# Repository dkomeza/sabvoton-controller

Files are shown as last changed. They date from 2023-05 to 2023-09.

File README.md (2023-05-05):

# sabvoton-controller

A controller for the sabvoton ebike esc.

## Pinout reference

```
---------------------------------------------------
| 01 | 02 | 03 | 04 | 05 | 06 | 07 | 08 | 09 | 10 |
---------------------------------------------------
| 11 | 12 | 13 | 14 | 15 | 16 | 17 | 18 | 19 | 20 |
---------------------------------------------------
| 21 | 22 | 23 | 24 | 25 | 26 | 27 | 28 | 29 | 30 |
---------------------------------------------------
```

- 01: speed (0V - Battery voltage)
- 02: programming (brown-blue)
- 03: low speed (controlled by gnd)
- 04: high speed (controlled by gnd)
- 05: brake (controlled by gnd)
- 06: service (unused)
- 07: empty
- 08: 5V
- 09: 5V square hall sensor (speedometer)
- 10: empty
- 11: battery voltage
- 12: programming (blue-yellow)
- 13: programming (green-black)
- 14: programming (red-black)
- 15: brake (controlled by 12v)
- 16: reverse (controlled by gnd)
- 17: gnd
- 18: gnd
- 19: throttle (0V - 5V)?
- 20: ignition (controlled by battery voltage)
- 21: engine phase (anti-theft)
- 22: empty
- 23: regen (controlled by gnd)
- 24: soft-start (connected to 26)
- 25: cruise control (controlled by gnd)
- 26: soft-start (connected to 24)
- 27: gnd
- 28: gnd
- 29: alarm (controlled by gnd)
- 30: service (unused)

## Working with the controller

### Connectors

- [x] 1: programming connector (same as the original)
- [x] 2: usb connector (for programming the arduino)

### Functions:

- [x] 1: set current gear (low, mid, high) - pins 03, 04
- [x] 2: set motor power based on the torque sensor input - pin 19
- [x] 3: read battery voltage - pin 11
- [x] 4: turn controller on/off - pin 20
- [x] 5: enable/disable soft start - pins 24, 26
- [x] 6: get engine temperature - white wire
- [x] 7: get engine rpm - white wire
- [x] 8: get controller temperature - additional sensor
- [x] 9: get battery temperature - additional sensor
- [x] 10: send data to the display - additional display
- [x] 11: get data from the display - additional display

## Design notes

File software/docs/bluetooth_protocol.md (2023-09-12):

# Bluetooth Serial protocol

```
-----------------------------
| Num | Value | Description |
-----------------------------
|  0  |  0x41 | Start byte  |
|  1  |  0xYY | Message ID  |
|  2  |  0xYY | Instruction |
| 3 - |  0xYY | Parameters  |
| n-1 |  0x0D | End byte 1  |
|  n  |  0x0A | End byte 2  |
-----------------------------
```

## Message ID

```
-----------------------
| Value | Description |
-----------------------
|  0x01 | Ping        |
|  0x02 | Settings    |
|  0x03 | Control     |
|  0x04 | Status      |
-----------------------
```

### Ping

```
-----------------------
| Value | Description |
-----------------------
|  0x01 | Ping        |
-----------------------
```

### Settings

```
-----------------------
| Value | Description |
-----------------------
| 0x01  | Throttle    |
-----------------------
```

#### Throttle

##### Parameter 0

```
---------------------------------
| Value | Description           |
---------------------------------
| 0x01  | Throttle min          |
| 0x02  | Throttle max          |
| 0x03  | Throttle save         |
---------------------------------
```

##### Parameter 1

```
--------------------------
| Value | Description    |
--------------------------
| 0x00  | Throttle value |
--------------------------
```

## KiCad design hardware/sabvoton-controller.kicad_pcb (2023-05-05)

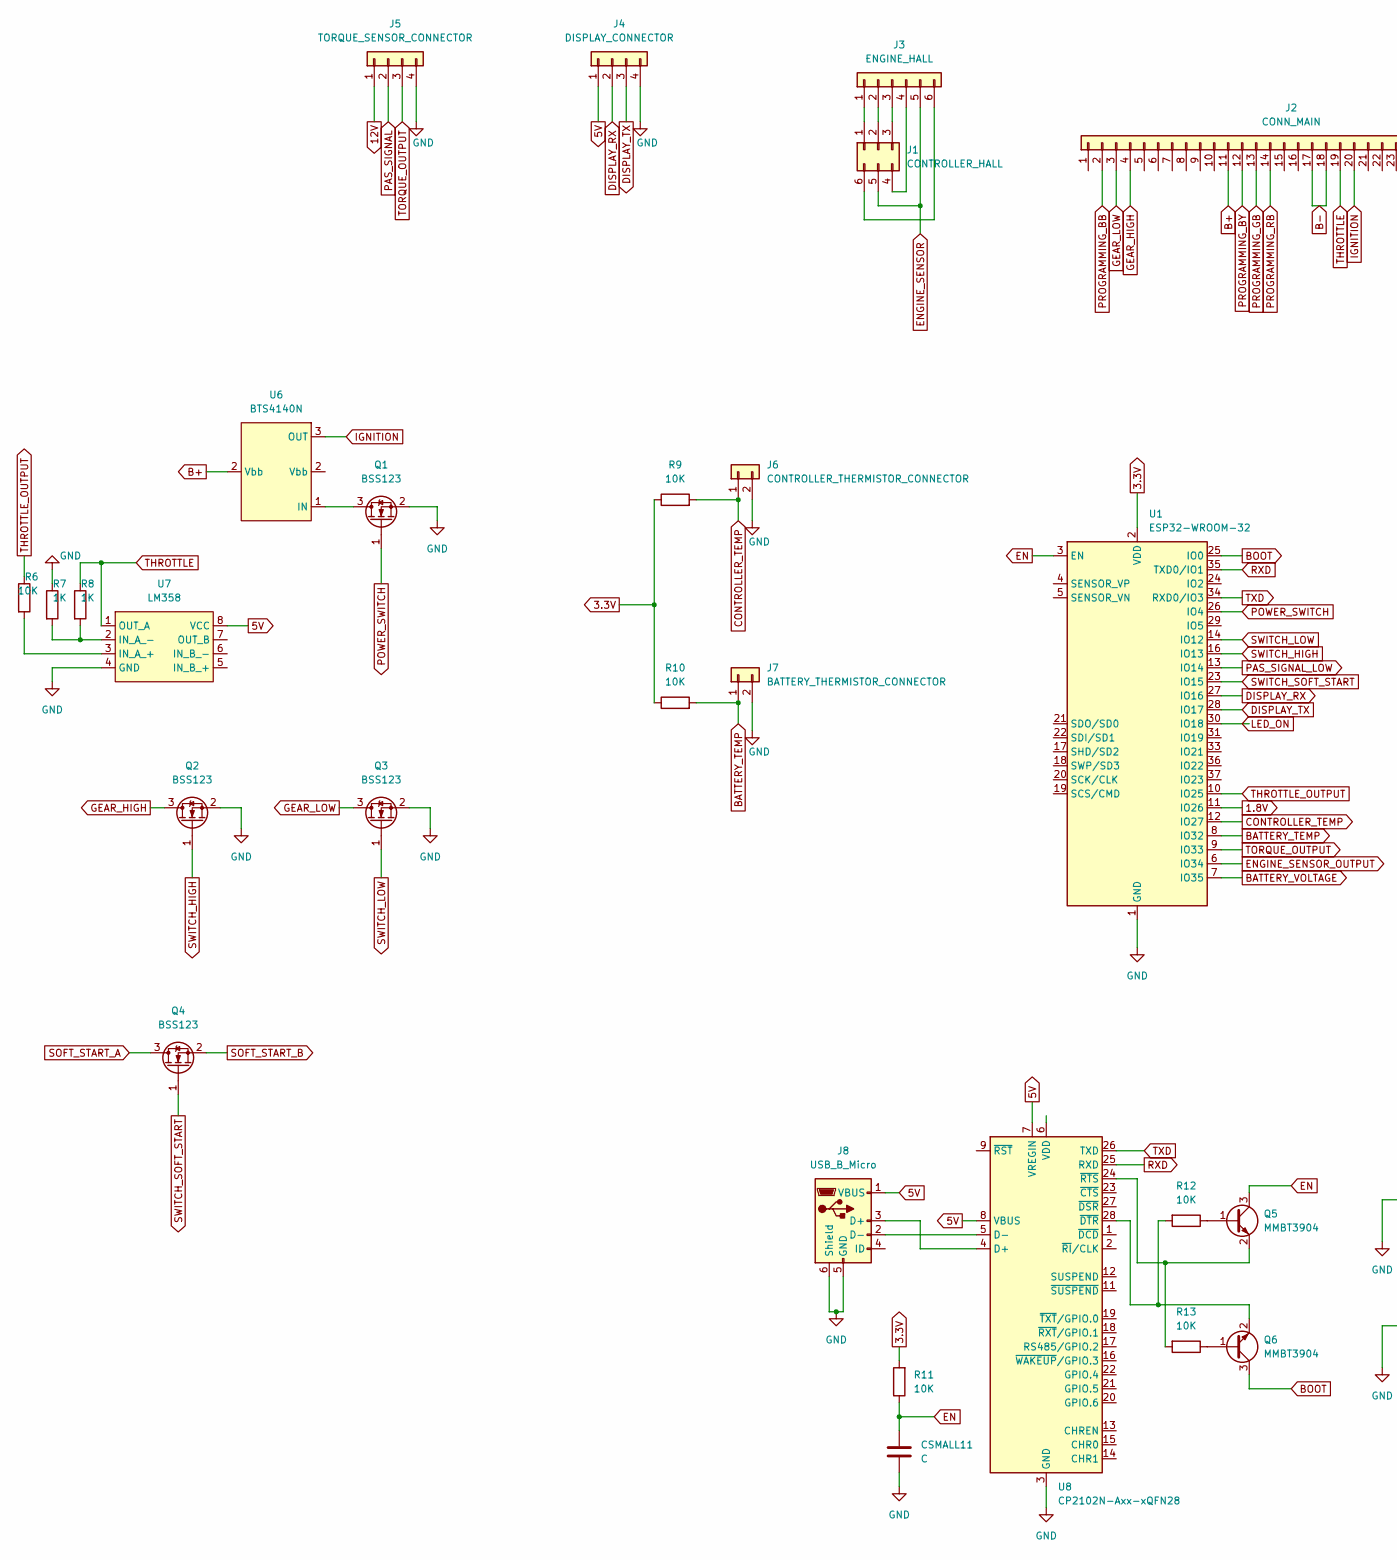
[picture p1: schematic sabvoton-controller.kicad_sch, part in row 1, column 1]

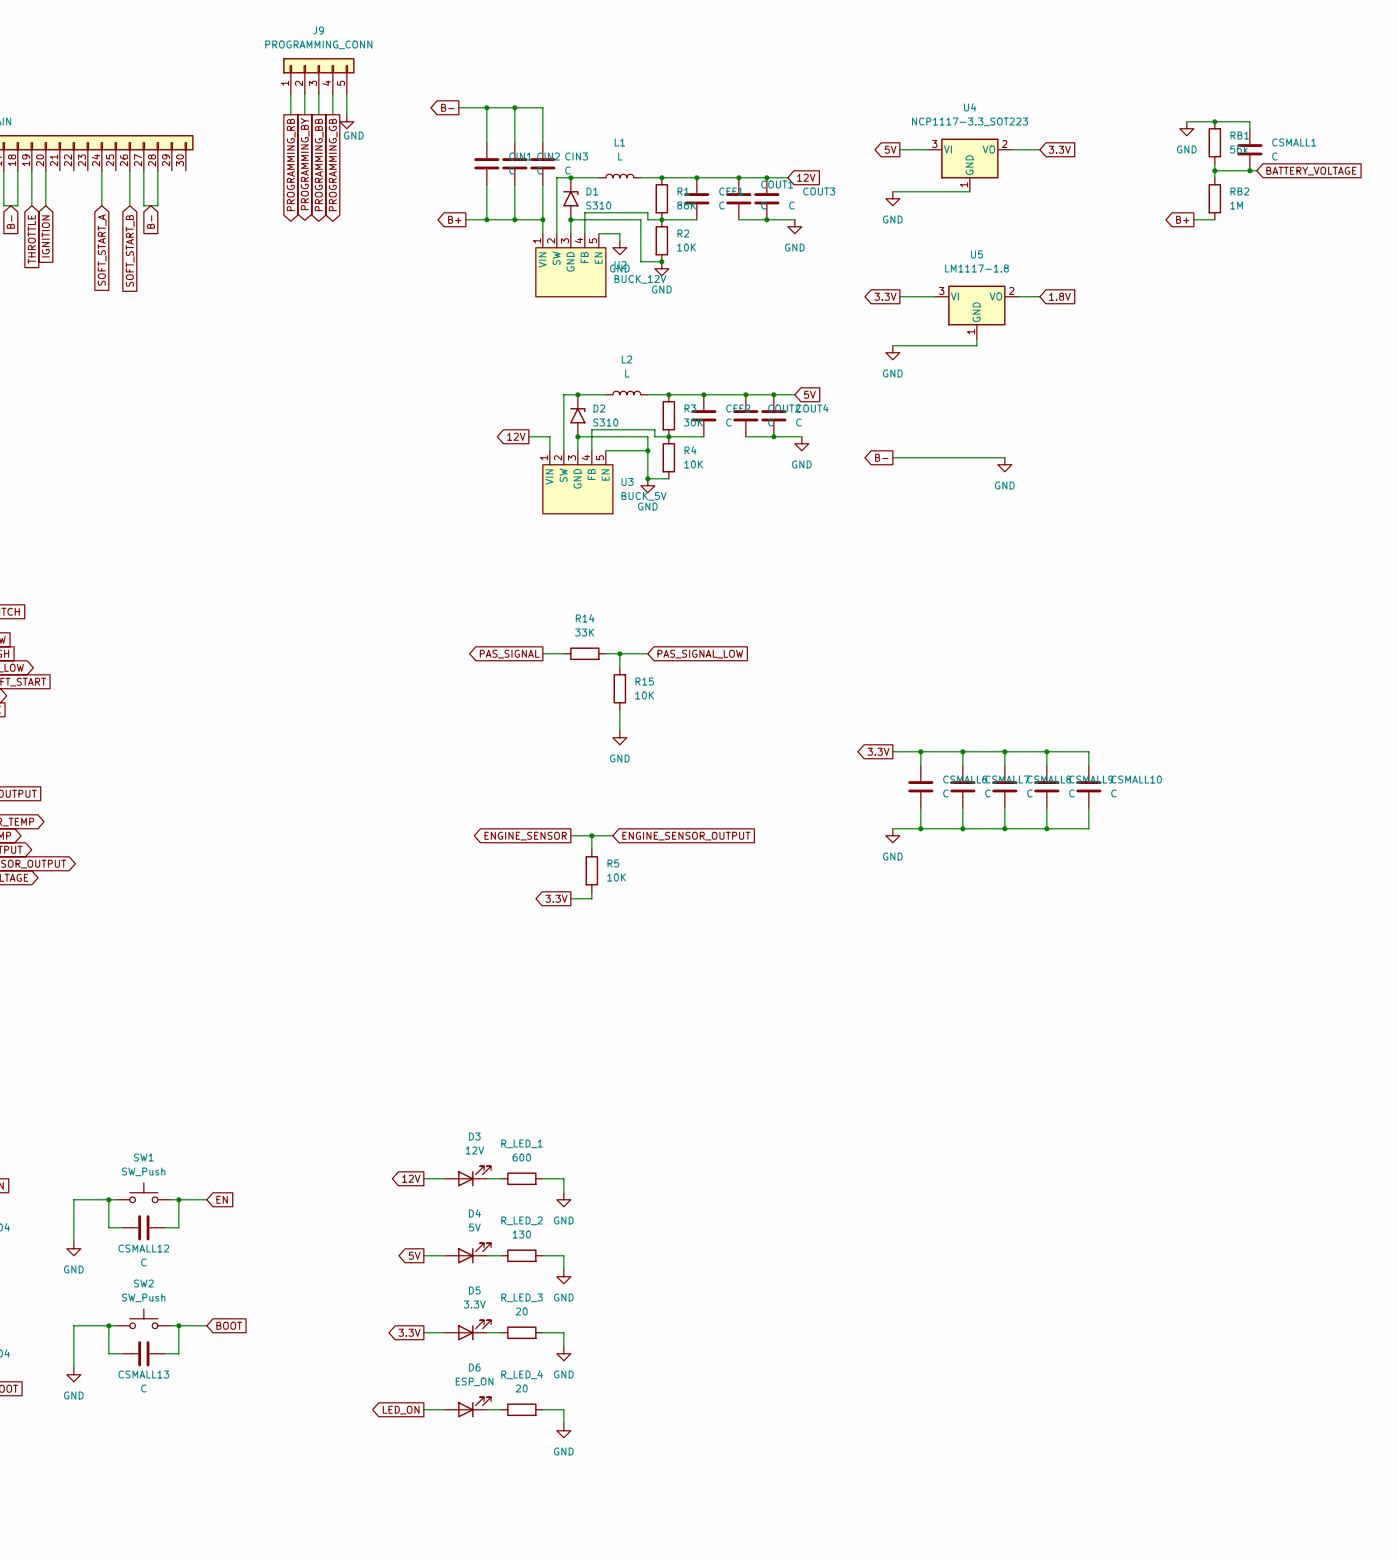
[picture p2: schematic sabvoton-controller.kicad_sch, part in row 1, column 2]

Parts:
CFF1, CFF2: C; C_1206_3216Metric_Pad1.33x1.80mm_HandSolder
CIN1, CIN2, CIN3: C; C_1210_3225Metric_Pad1.33x2.70mm_HandSolder
COUT1, COUT2, COUT3, COUT4: C; C_1210_3225Metric_Pad1.33x2.70mm_HandSolder
CSMALL1, CSMALL6, CSMALL7, CSMALL8, CSMALL9, CSMALL10, CSMALL11, CSMALL12, CSMALL13: C; C_1206_3216Metric
D1, D2: S310; S2M
D3: 12V; LED_1206_3216Metric
D4: 5V; LED_1206_3216Metric
D5: 3.3V; LED_1206_3216Metric
D6: ESP_ON; LED_1206_3216Metric
J1: CONTROLLER_HALL; HALL_2x6
J2: CONN_MAIN; MAIN_3x10
J3: ENGINE_HALL; SolderWire-0.5sqmm_1x06_P4.8mm_D0.9mm_OD2.3mm
J4: DISPLAY_CONNECTOR; SolderWire-1x4-buttons
J5: TORQUE_SENSOR_CONNECTOR; SolderWire-1x4-buttons
J6: CONTROLLER_THERMISTOR_CONNECTOR; SolderWire-0.25sqmm_1x02_P4.2mm_D0.65mm_OD1.7mm
J7: BATTERY_THERMISTOR_CONNECTOR; SolderWire-0.25sqmm_1x02_P4.2mm_D0.65mm_OD1.7mm
J8: USB_B_Micro; USB_Micro-B_Molex-105017-0001
J9: PROGRAMMING_CONN; Pogramming_1x5
L1, L2: L; L_7.3x7.3_H3.5
Q1, Q2, Q3, Q4: BSS123; SOT-23
Q5, Q6: MMBT3904; SOT-23
R1: 86K; R_1206_3216Metric_Pad1.30x1.75mm_HandSolder
R2, R4, R5, R6, R9, R10, R11, R12, R13, R15: 10K; R_1206_3216Metric_Pad1.30x1.75mm_HandSolder
R3: 30K; R_1206_3216Metric_Pad1.30x1.75mm_HandSolder
R7, R8: 1K; R_1206_3216Metric_Pad1.30x1.75mm_HandSolder
R14: 33K; R_1206_3216Metric_Pad1.30x1.75mm_HandSolder
RB1: 56k; R_1206_3216Metric_Pad1.30x1.75mm_HandSolder
RB2: 1M; R_1206_3216Metric_Pad1.30x1.75mm_HandSolder
R_LED_1: 600; R_0805_2012Metric
R_LED_2: 130; R_1206_3216Metric
R_LED_3, R_LED_4: 20; R_1206_3216Metric
SW1, SW2: SW_Push; BUTTON_SW
U1: ESP32-WROOM-32
U2: BUCK_12V; TO-252-5_TabPin3
U3: BUCK_5V; TO-252-5_TabPin3
U4: NCP1117-3.3_SOT223; SOT-223-3_TabPin2
U5: LM1117-1.8; SOT-223-3_TabPin2
U6: BTS4140N; SOT-223-3_TabPin2
U7: LM358; SO-8_5.3x6.2mm_P1.27mm
U8: CP2102N-Axx-xQFN28; QFN-28-1EP_5x5mm_P0.5mm_EP3.35x3.35mm

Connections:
1.8V: U1.11 (IO26), U5.2 (VO)
3.3V: CSMALL6.1, CSMALL7.1, CSMALL8.1, CSMALL9.1, CSMALL10.1, D5.2 (A), R5.2, R9.1, R10.1, R11.2, U1.2 (VDD), U4.2 (VO), U5.3 (VI)
5V: CFF2.2, COUT2.1, COUT4.1, D4.2 (A), J4.1, J8.1 (VBUS), L2.2, R3.1, U4.3 (VI), U7.8 (VCC), U8.7 (VREGIN), U8.8 (VBUS)
12V: CFF1.2, COUT1.1, COUT3.1, D3.2 (A), J5.1, L1.2, R1.1, U3.1 (VIN)
B+: CIN1.2, CIN2.2, CIN3.2, J2.11, RB2.2, U2.1 (VIN), U6.2 (Vbb)
B-: CIN1.1, CIN2.1, CIN3.1, COUT1.2, COUT2.2, COUT3.2, COUT4.2, CSMALL1.1, CSMALL6.2, CSMALL7.2, CSMALL8.2, CSMALL9.2, CSMALL10.2, CSMALL11.2, CSMALL12.1, CSMALL13.1, D1.2 (A2), D2.2 (A2), J2.17, J2.18, J2.27, J2.28, J4.4, J5.4, J6.2, J7.2, J8.5 (GND), J8.6 (Shield), J9.5, Q1.2 (S), Q2.2 (S), Q3.2 (S), R2.2, R4.2, R7.1, R15.1, RB1.2, R_LED_1.2, R_LED_2.2, R_LED_3.2, R_LED_4.2, SW1.1, SW2.1, U1.1 (GND), U1.15 (GND), U1.38 (GND), U1.39 (GND), U2.3 (GND), U2.5 (EN), U3.3 (GND), U3.5 (EN), U4.1 (GND), U5.1 (GND), U7.4 (GND), U8.3 (GND), U8.29 (GND)
BATTERY_TEMP: J7.1, R10.2, U1.8 (IO32)
BATTERY_VOLTAGE: CSMALL1.2, RB1.1, RB2.1, U1.7 (IO35)
BOOT: CSMALL13.2, Q6.3 (C), SW2.2, U1.25 (IO0)
CONTROLLER_TEMP: J6.1, R9.2, U1.12 (IO27)
DISPLAY_RX: J4.2, U1.27 (IO16)
DISPLAY_TX: J4.3, U1.28 (IO17)
EN: CSMALL11.1, CSMALL12.2, Q5.3 (C), R11.1, SW1.2, U1.3 (EN)
ENGINE_SENSOR: J1.5, J3.5, R5.1, U1.6 (IO34)
GEAR_HIGH: J2.4, Q2.3 (D)
GEAR_LOW: J2.3, Q3.3 (D)
IGNITION: J2.20, U6.3 (OUT)
LED_ON: D6.2 (A), U1.30 (IO18)
unnamed: CFF1.1, R1.2, R2.1, U2.4 (FB)
unnamed: CFF2.1, R3.2, R4.1, U3.4 (FB)
unnamed: D1.1 (A1), L1.1, U2.2 (SW)
unnamed: D2.1 (A1), L2.1, U3.2 (SW)
unnamed: D3.1 (K), R_LED_1.1
unnamed: D4.1 (K), R_LED_2.1
unnamed: D5.1 (K), R_LED_3.1
unnamed: D6.1 (K), R_LED_4.1
unnamed: J1.1, J3.1
unnamed: J1.2, J3.2
unnamed: J1.3, J3.3
unnamed: J1.4, J3.4
unnamed: J1.6, J3.6
unnamed: J8.2 (D-), U8.5 (D-)
unnamed: J8.3 (D+), U8.4 (D+)
unnamed: Q1.3 (D), U6.1 (IN)
unnamed: Q5.1 (B), R12.1
unnamed: Q5.2 (E), R13.2, U8.24 (~RTS)
unnamed: Q6.1 (B), R13.1
unnamed: Q6.2 (E), R12.2, U8.28 (~DTR)
unnamed: R6.2, U7.3 (IN_A_+)
unnamed: R7.2, R8.2, U7.2 (IN_A_-)
PAS_SIGNAL: J5.2, R14.1
PAS_SIGNAL_LOW: R14.2, R15.2, U1.13 (IO14)
POWER_SWITCH: Q1.1 (G), U1.26 (IO4)
PROGRAMMING_BB: J2.2, J9.3
PROGRAMMING_BY: J2.12, J9.2
PROGRAMMING_GB: J2.13, J9.4
PROGRAMMING_RB: J2.14, J9.1
RXD: U1.35 (TXD0/IO1), U8.25 (RXD)
SOFT_START_A: J2.24, Q4.3 (D)
SOFT_START_B: J2.26, Q4.2 (S)
SWITCH_HIGH: Q2.1 (G), U1.16 (IO13)
SWITCH_LOW: Q3.1 (G), U1.14 (IO12)
SWITCH_SOFT_START: Q4.1 (G), U1.23 (IO15)
THROTTLE: J2.19, R8.1, U7.1 (OUT_A)
THROTTLE_OUTPUT: R6.1, U1.10 (IO25)
TORQUE_OUTPUT: J5.3, U1.9 (IO33)
TXD: U1.34 (RXD0/IO3), U8.26 (TXD)

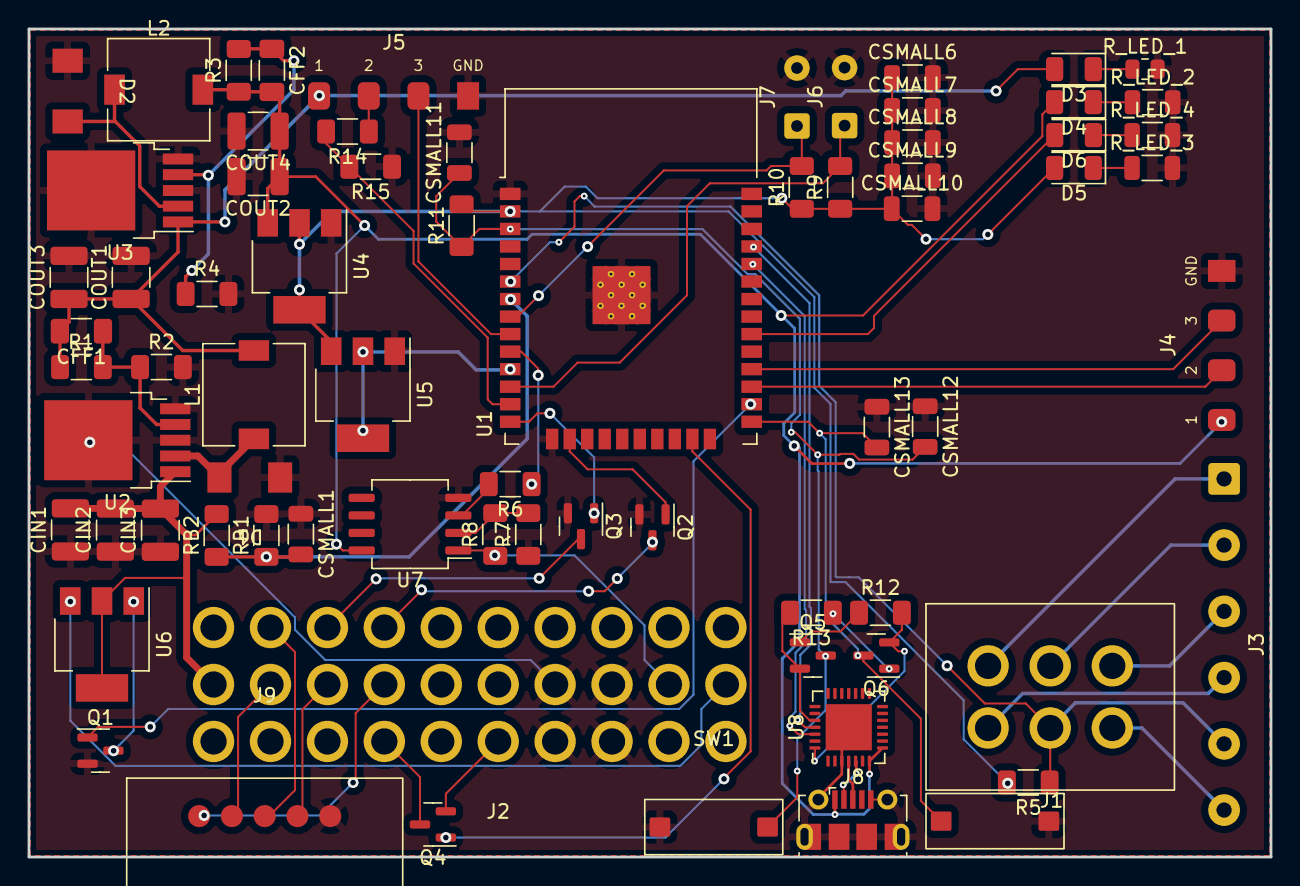
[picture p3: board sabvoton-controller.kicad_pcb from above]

Board: 2 copper layers, 90.0 x 60.0 mm, 72 parts (0 on the bottom side), 57 nets.

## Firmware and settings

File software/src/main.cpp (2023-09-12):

#include <Arduino.h>
#include <EEPROM.h>

#include "connection/OTA.h"
#include "connection/bluetooth.h"

#include "data/data.h"
#include "controller/controller.h"
#include "io/io.h"
#include "display/display.h"

Data data;
Controller controller;
IO io;
Display display;
Bluetooth bluetooth;

long lastTime = 0;

bool isConnected = false;

void setup()
{
    Serial.begin(115200);

    // set up EEPROM
    EEPROM.begin(512);

    /* Set up OTA and check whether connected */
    isConnected = OTA::setupOTA();

    if (!isConnected)
    {
        data.init();
        io.setup();
        controller.setup();
        bluetooth.setup();
        display.init();

        data.mainData.gear = 3;
    }

    lastTime = millis();
}

void loop()
{
    if (isConnected)
    {
        OTA::handle();
    }
    else
    {
        if (!bluetooth.settingsEnabled)
        {
            io.handle();
            controller.handle();
            display.handle();
        }
    }

    delay(10);
}

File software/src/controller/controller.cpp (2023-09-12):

#include "controller.h"

void Controller::setup()
{
    // Set up pins
    pinMode(POWER_PIN, OUTPUT);
    pinMode(GEAR_LOW_PIN, OUTPUT);
    pinMode(GEAR_HIGH_PIN, OUTPUT);
    pinMode(THROTTLE_PIN, OUTPUT);
    pinMode(SOFT_START_PIN, OUTPUT);

    // Turn on the controller
    digitalWrite(POWER_PIN, HIGH);

    // Enable soft start
    digitalWrite(SOFT_START_PIN, LOW);

    // Set gear to neutral
    setGear(Gear::Medium);

    // Set throttle to 0
    setThrottle(0);

    // Read throttle settings from EEPROM
    THROTTLE_MIN = EEPROM.read(THROTTLE_MIN_ADDRESS);
    THROTTLE_MAX = EEPROM.read(THROTTLE_MAX_ADDRESS);

    // Update throttle based on gear
    changeGear();
}

void Controller::handle()
{
    // Return if in settings mode or empty mode
    if (data.mode == MODE::SETTINGS || data.mode == MODE::MENU)
        return;

    if (millis() < lastTime)
        lastTime = millis();

    if (millis() - lastTime < interval)
        return;

    // Update throttle
    handleThrottle();

    lastTime = millis();
}

void Controller::handleThrottle()
{
    if (data.brake || data.mainData.gear == 0 || data.torque == 0)
    {
        dacWrite(THROTTLE_PIN, 0);
        return;
    }

    int torqueValue = map(data.torque, torqueMin, torqueMax, 0, 255);

    if (torqueValue < 0)
        torqueValue = 0;
    else if (torqueValue > 255)
        torqueValue = 255;

    int throttleValue = map(torqueValue, 0, 255, THROTTLE_MIN, throttleMax);

    dacWrite(THROTTLE_PIN, throttleValue);
}

void Controller::changeGear()
{
    switch (data.mainData.gear)
    {
    case 1:
        throttleMax = (THROTTLE_MAX - THROTTLE_MIN) * 0.33 + THROTTLE_MIN;
        setGear(Low);
        torqueMax = 255;
        break;
    case 2:
        throttleMax = (THROTTLE_MAX - THROTTLE_MIN) * 0.66 + THROTTLE_MIN;
        setGear(Low);
        torqueMax = 255;
        break;
    case 3:
        throttleMax = THROTTLE_MAX;
        setGear(Low);
        torqueMax = 255;
        break;
    case 4:
        throttleMax = THROTTLE_MAX;
        setGear(Medium);
        torqueMax = 172;
        break;
    case 5:
        throttleMax = THROTTLE_MAX;
        setGear(High);
        torqueMax = 128;
        break;
    }
}

void Controller::setGear(Gear gear)
{
    switch (gear)
    {
    case Gear::Low:
        digitalWrite(GEAR_LOW_PIN, HIGH);
        digitalWrite(GEAR_HIGH_PIN, LOW);
        break;
    case Gear::Medium:
        digitalWrite(GEAR_LOW_PIN, LOW);
        digitalWrite(GEAR_HIGH_PIN, LOW);
        break;
    case Gear::High:
        digitalWrite(GEAR_LOW_PIN, LOW);
        digitalWrite(GEAR_HIGH_PIN, HIGH);
        break;
    }
}

void Controller::setThrottle(int value)
{
    dacWrite(THROTTLE_PIN, value);
}

void Controller::setThrottleMin(int value)
{
    THROTTLE_MIN = value;
    setThrottle(THROTTLE_MIN);
}

void Controller::setThrottleMax(int value)
{
    THROTTLE_MAX = value;
    setThrottle(THROTTLE_MAX);
}

void Controller::saveThrottleSettings()
{
    EEPROM.write(THROTTLE_MIN_ADDRESS, THROTTLE_MIN);
    EEPROM.write(THROTTLE_MAX_ADDRESS, THROTTLE_MAX);
    EEPROM.commit();
    setThrottle(0);
}

void Controller::disableThrottle()
{
    setThrottle(0);
}

int Controller::readThrottleMin()
{
    return THROTTLE_MIN;
}

int Controller::readThrottleMax()
{
    return THROTTLE_MAX;
}

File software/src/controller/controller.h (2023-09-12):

#ifndef CONTROLLER_H
#define CONTROLLER_H

#include <Arduino.h>
#include <EEPROM.h>

#include "data/data.h"

namespace Controller_Constants
{
    const int POWER_PIN = 4;

    const int GEAR_LOW_PIN = 12;
    const int GEAR_HIGH_PIN = 13;

    const int THROTTLE_PIN = 25;

    const int SOFT_START_PIN = 15;

    enum Gear
    {
        Low = 1,
        Medium = 2,
        High = 3
    };

    const int THROTTLE_MIN_ADDRESS = 11;
    const int THROTTLE_MAX_ADDRESS = 12;
}

using namespace Controller_Constants;

class Controller
{
public:
    void setup();
    void handle();

    void setThrottleMin(int value);
    void setThrottleMax(int value);
    void saveThrottleSettings();
    void disableThrottle();
    int readThrottleMin();
    int readThrottleMax();

    void changeGear();

private:
    long unsigned int lastTime = 0;
    int interval = 10;

    int THROTTLE_MIN = 0;
    int THROTTLE_MAX = 255;

    int throttleMin = 0;
    int throttleMax = 255;

    int torqueMin = 0;
    int torqueMax = 255;

    void handleThrottle();

    void setThrottle(int value);

    void setGear(Gear gear);
};

extern Controller controller;

#endif

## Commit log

2023-04-09 Added controller connectors && microcontroller
    [sabvoton-controller.kicad_pcb, sabvoton-controller.kicad_sch]
2023-04-09 Added 12V conversion part
    [sabvoton-controller.kicad_sch]
2023-04-09 Added 5V conversion part
    [sabvoton-controller.kicad_sch]
2023-04-09 Added 3.3V conversion
    [sabvoton-controller.kicad_sch]
2023-04-09 Added 1.8V converter (voltage reference)
    [sabvoton-controller.kicad_sch]
2023-04-09 Connect negative battery to gnd
    [sabvoton-controller.kicad_sch]
2023-04-09 Added more controller connections
    [sabvoton-controller.kicad_sch]
2023-04-09 Added power to the ESP32
    [sabvoton-controller.kicad_sch]
2023-04-10 Added power switch circuit
    [sabvoton-controller.kicad_sch]
2023-04-10 Connect power switch to the esp
    [sabvoton-controller.kicad_sch]
2023-04-10 Added battery voltage input
    [sabvoton-controller.kicad_sch]
2023-04-10 Added engine temperature & speed sensor
    [sabvoton-controller.kicad_sch]
2023-04-10 Added gear switch
    [sabvoton-controller.kicad_sch]
2023-04-10 Added throttle output
    [sabvoton-controller.kicad_sch]
2023-04-10 Added torque sensor connection
    [sabvoton-controller.kicad_sch]
2023-04-10 Added soft start switch
    [sabvoton-controller.kicad_sch]
2023-04-10 Added battery & controller thermistor connections
    [sabvoton-controller.kicad_sch]
2023-04-12 Added USB connector
    [sabvoton-controller.kicad_sch]
2023-04-16 Added programing connector
    [sabvoton-controller.kicad_sch]
2023-05-05 Finished PCB design
    [sabvoton-controller-B_Cu.gbr, sabvoton-controller-B_Mask.gbr, sabvoton-controller-B_Paste.gbr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]
2023-05-16 :sparkles: Add controller power switch
2023-05-16 :sparkles: Add controller gear selection
2023-05-16 :bug: Fix incorrect power pin
2023-05-16 :sparkles: Add throttle output
2023-05-16 :sparkles: Add soft start switch
2023-05-16 :sparkles: Add voltage reading
2023-05-16 :sparkles: Add temperature sensor reading
2023-06-22 :art: Change folder names
    [sabvoton-controller-B_Cu.gbr, sabvoton-controller-B_Mask.gbr, sabvoton-controller-B_Paste.gbr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]
2023-06-22 :art: Move KiCad files directly to the hardware folder.
    [sabvoton-controller-B_Cu.gbr, sabvoton-controller-B_Mask.gbr, sabvoton-controller-B_Paste.gbr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]
2023-06-24 :sparkles: Read torque sensor input
2023-07-21 :bug: Fix ADC2 not working when WiFi is on
    [main.cpp]
